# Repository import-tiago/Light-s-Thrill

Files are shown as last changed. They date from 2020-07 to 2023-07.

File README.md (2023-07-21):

# Light's Thrill

 

Light's Thrill is an USB HID controller for RGB LED-strips, compatible with Corsair iCUE application.

#### Compatible with: 
* [iCUE](https://www.corsair.com/br/pt/icue)
* [OpenRGB](https://gitlab.com/CalcProgrammer1/OpenRGB)
* [JackNet RGB Sync](https://rgbsync.com/)
* [RGB Infrared Controller](https://github.com/import-tiago/Light-s-Thrill/blob/master/Assets/RGB%20Infrared%20Controller%20Example.jpg)

## 3D Printed Enclosure
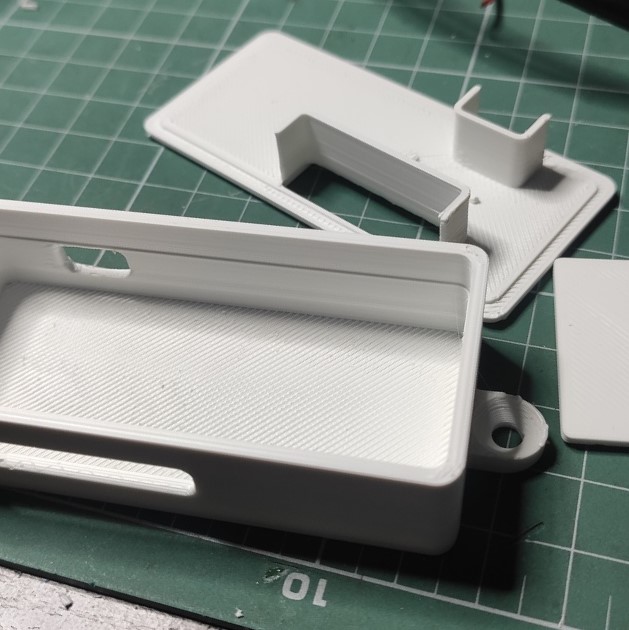
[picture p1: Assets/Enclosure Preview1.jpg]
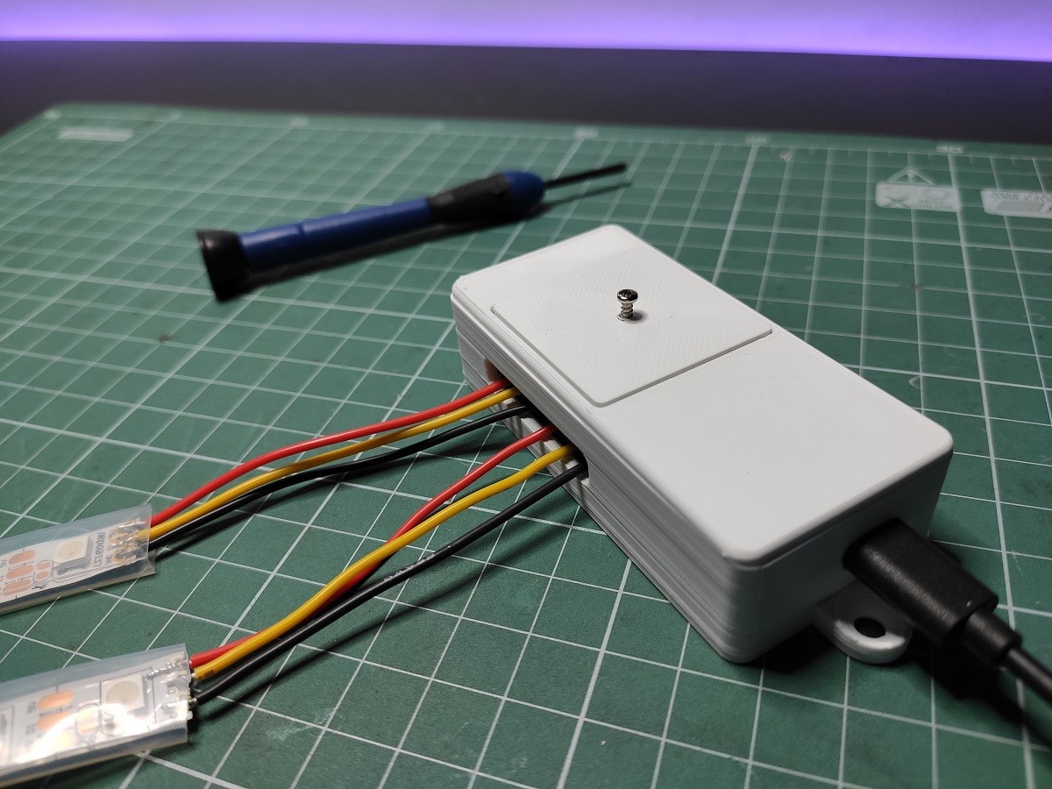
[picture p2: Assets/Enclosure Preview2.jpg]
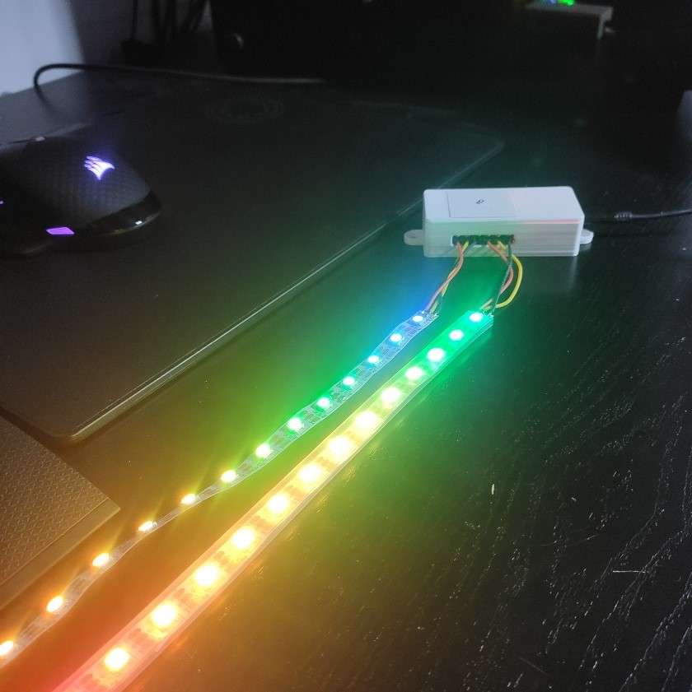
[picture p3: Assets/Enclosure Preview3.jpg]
 |  | 
--- | --- | ---

## Schematic
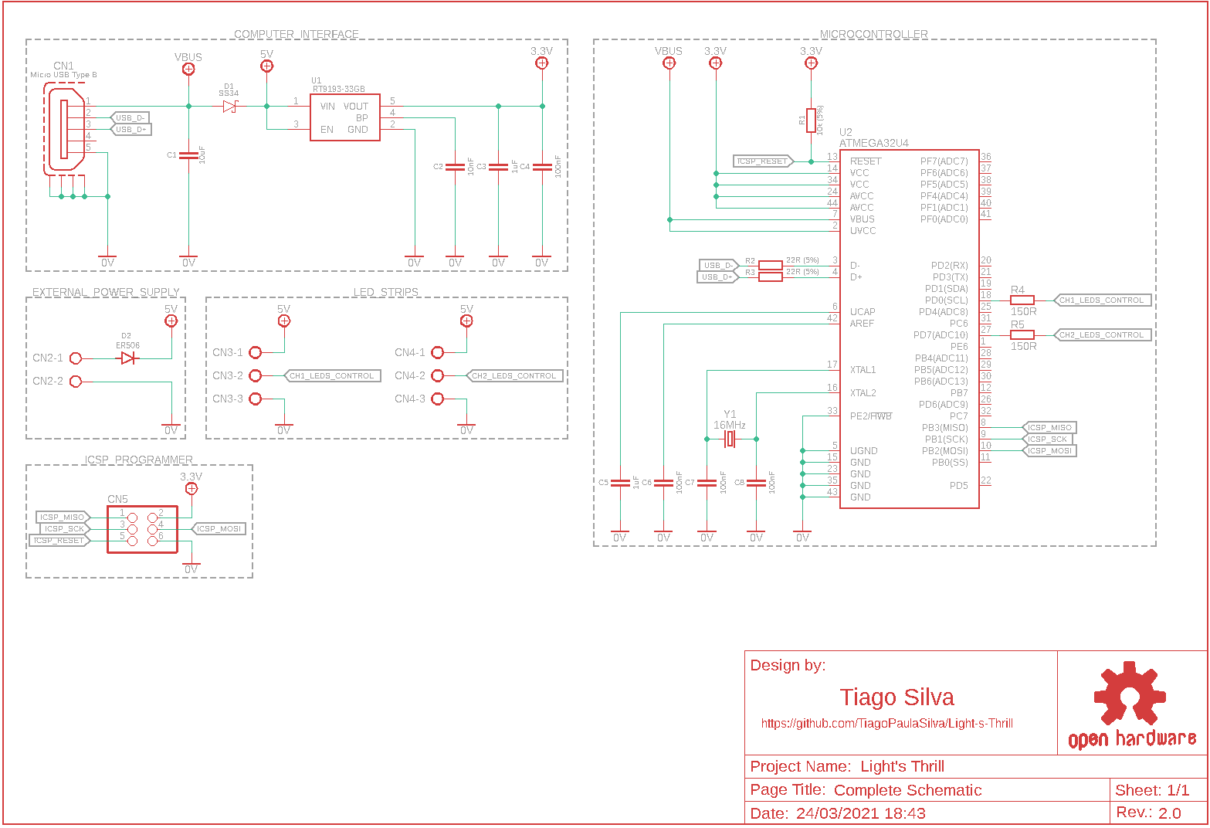
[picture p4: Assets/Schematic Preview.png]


## SETUP Parts


## MCU SETUP
- Burn the Arduino Leornado bootloader at ATmega32U4 with an Arduino UNO as ISP programmer using SPI circuit connection.
- Install the Corsair Lighting Protocol Boards to the Arduino IDE from: ```https://raw.githubusercontent.com/Legion2/CorsairLightingProtocolBoards/master/package_Legion2_CorsairLightingProtocolBoards_index.json```.
- Upload the ```Firmware\Firmware.ino``` to the ATmega32u4 as following:
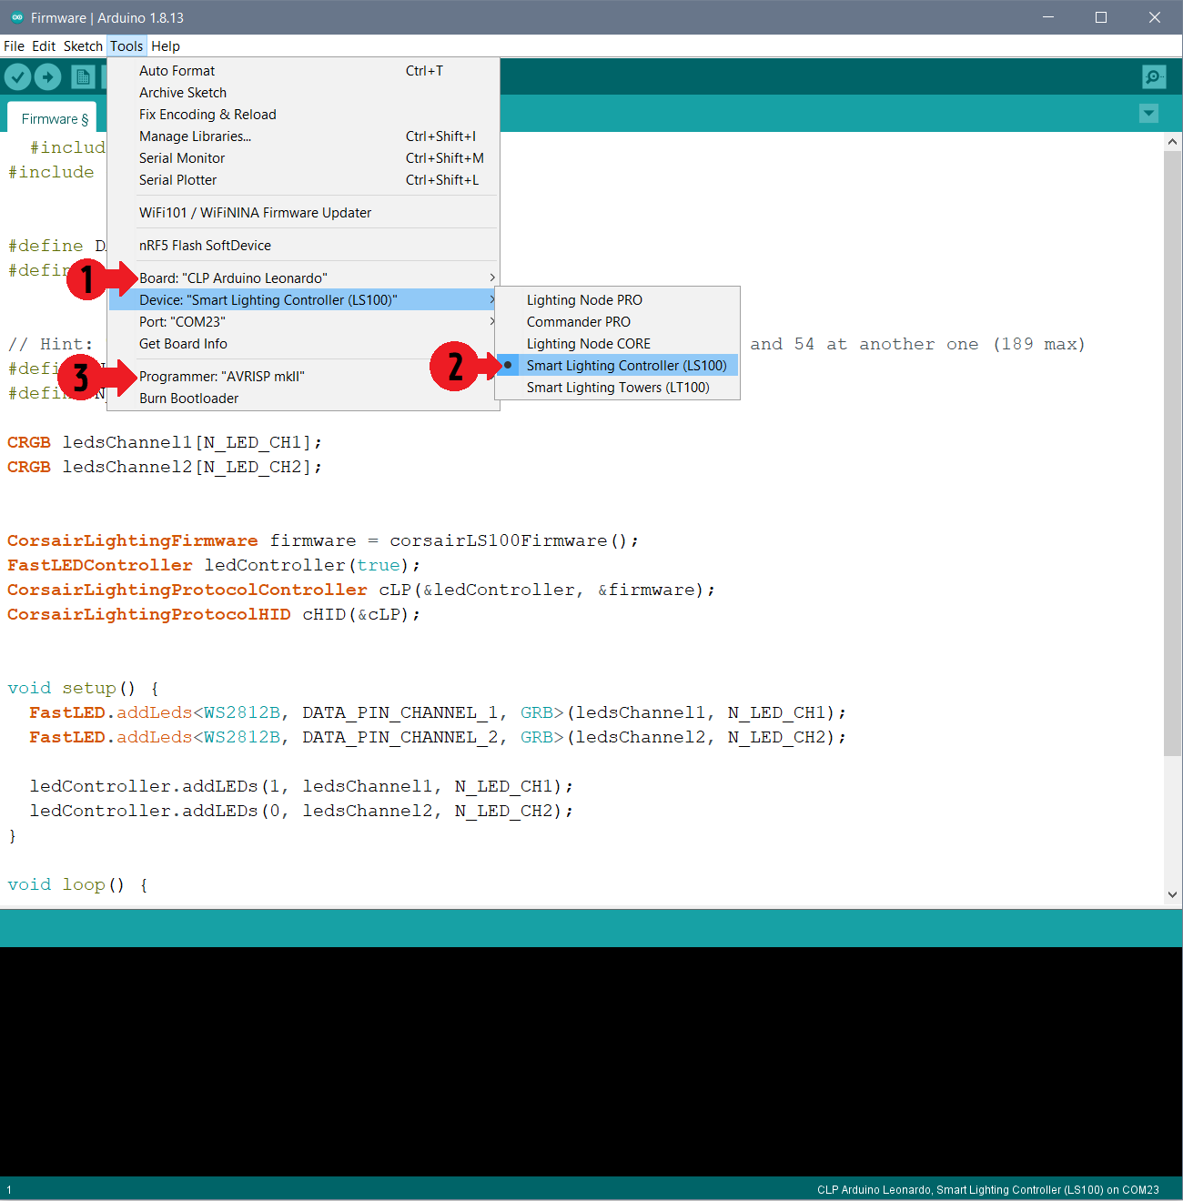
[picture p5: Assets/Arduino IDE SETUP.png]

- Done. The device is now ready to be recognized by Corsair iCUE application.

## Corsair iCUE SETUP
- To have the maximum (2x 89) of LEDs controlled by the iCUE, configure it as follows:


## Video - Demo
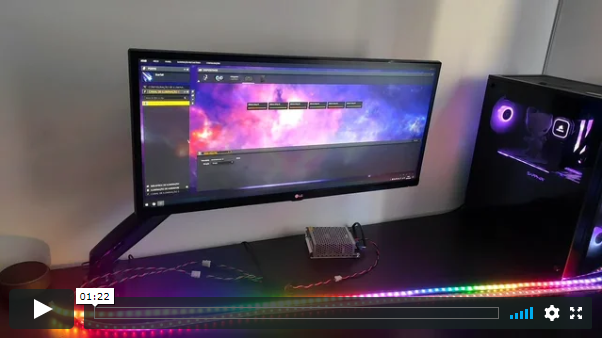
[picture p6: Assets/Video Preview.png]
Watch the video
<p align="center"></p>

### Contributing
0. Give this project a :star:
1. Create an issue and describe your idea.
2. [Fork it](https://github.com/import-tiago/Light-s-Thrill/fork).
3. Create your feature branch (`git checkout -b my-new-feature`).
4. Commit your changes (`git commit -a -m "Added feature title"`).
5. Publish the branch (`git push origin my-new-feature`).
6. Create a new pull request.
7. Done! :heavy_check_mark:

### License Information
<br /><span xmlns:dct="http://purl.org/dc/terms/" property="dct:title">Light's Thrill</span> by <a xmlns:cc="http://creativecommons.org/ns#" href="https://github.com/import-tiago" property="cc:attributionName" rel="cc:attributionURL">Tiago Silva</a> is licensed under a <a rel="license" href="http://creativecommons.org/licenses/by-sa/4.0/">Creative Commons Attribution-ShareAlike 4.0 International License</a>.<br />
Based on a work at <a xmlns:dct="http://purl.org/dc/terms/" href="[Corsair Lighting Protocol](https://github.com/import-tiago/CorsairLightingProtocol)" rel="dct:source">[Corsair Lighting Protocol](https://github.com/import-tiago/CorsairLightingProtocol)</a> and <a xmlns:dct="http://purl.org/dc/terms/" href="[Open Corsair Link](https://github.com/import-tiago/OpenCorsairLink)" rel="dct:source">[Open Corsair Link](https://github.com/import-tiago/OpenCorsairLink)</a>.<br />
Permissions beyond the scope of this license may be available at <a xmlns:cc="http://creativecommons.org/ns#" href="https://twitter.com/import_tiago" rel="cc:morePermissions">tiagodepaulasilva@gmail.com</a>.

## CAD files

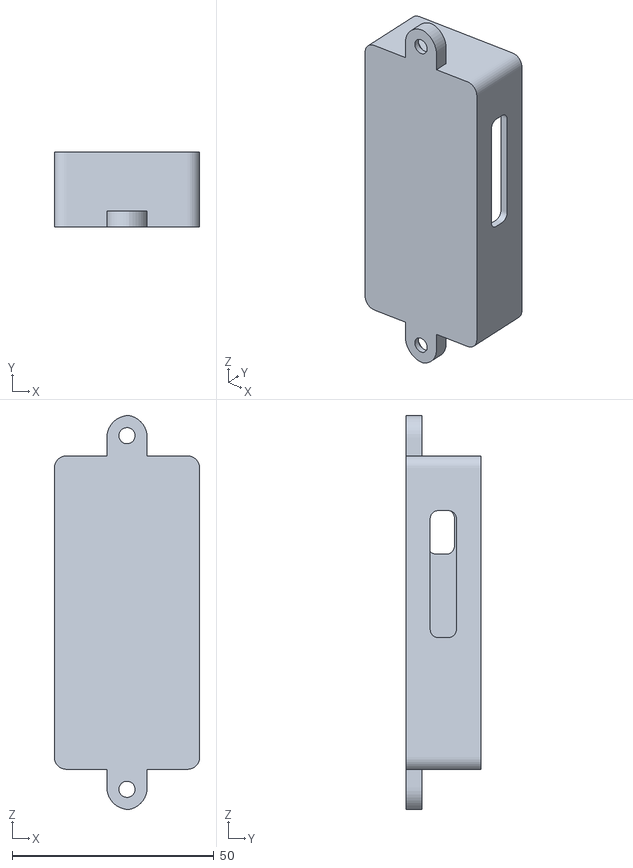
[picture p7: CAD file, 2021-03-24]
3D Models/Light's Thrill - Enclosure Box.stl
36.0 x 18.6 x 97.5

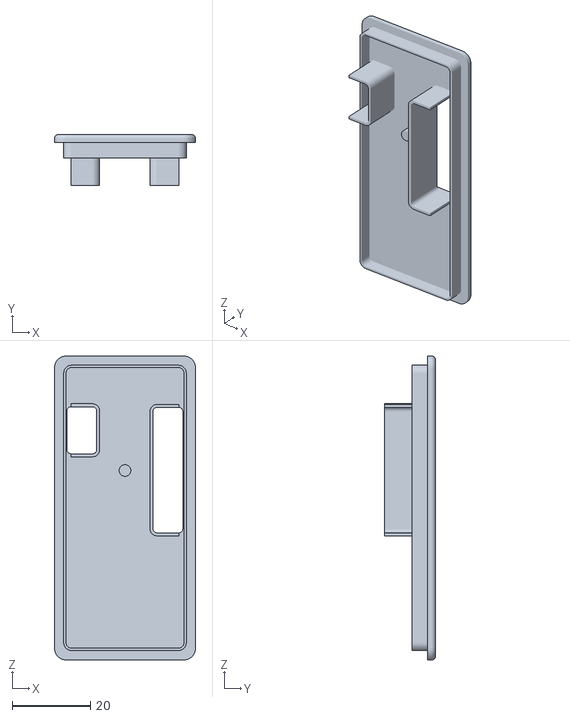
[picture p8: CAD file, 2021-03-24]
3D Models/Light's Thrill - Enclosure Cover.stl
36.0 x 13.0 x 77.6

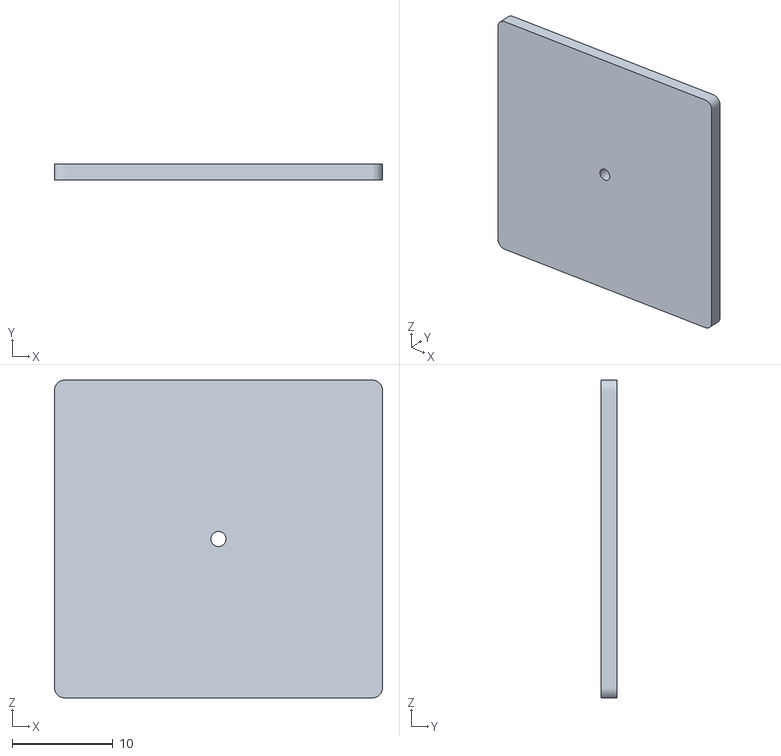
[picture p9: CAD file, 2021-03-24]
3D Models/Light's Thrill - Screws Cover.stl
32.5 x 1.60 x 31.5

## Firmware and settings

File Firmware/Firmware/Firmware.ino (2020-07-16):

#include <CorsairLightingProtocol.h>
#include <FastLED.h>
#include "IRremote.h"
#include <RGBLed.h>
#include <EEPROM.h>

#define LED_RED_PIN     5
#define LED_GREEN_PIN   9
#define LED_BLUE_PIN    10
#define IR_SENSOR_PIN   7

#define BRIGHTNESS_INCREASE   ((long)0xF700FF)
#define COLOR_RED             ((long)0xF720DF)
#define COLOR_ORANGE_RED      ((long)0xF710EF)
#define COLOR_ORANGE          ((long)0xF730CF)
#define COLOR_CORAL           ((long)0xF708F7)
#define COLOR_YELLOW          ((long)0xF728D7)
#define BRIGHTNESS_DECREASE   ((long)0xF7807F)
#define COLOR_GREEN           ((long)0xF7A05F)
#define COLOR_LIME            ((long)0xF7906F)
#define COLOR_CYAN            ((long)0xF7B04F)
#define COLOR_BABY_BLUE       ((long)0xF78877)
#define COLOR_CERULEAN        ((long)0xF7A857)
#define SWITCH_OFF            ((long)0xF740BF)
#define COLOR_BLUE            ((long)0xF7609F)
#define COLOR_AZURE           ((long)0xF750AF)
#define COLOR_BLUE_VIOLET     ((long)0xF7708F)
#define COLOR_BYZANTIUM       ((long)0xF748B7)
#define COLOR_PINK            ((long)0xF76897)
#define SWITCH_ON             ((long)0xF7C03F)
#define COLOR_WHITE           ((long)0xF7E01F)
#define EFFECT_FLASH          ((long)0xF7D02F)
#define EFFECT_STROBE         ((long)0xF7F00F)
#define EFFECT_FADE           ((long)0xF7C837)
#define EFFECT_SMOOTH         ((long)0xF7E817)

#define CONTROLLED_BY_INFRARED  0
#define CONTROLLED_BY_USB       1
bool Current_Control_Device = CONTROLLED_BY_USB;

IRrecv irrecv(7);
decode_results results;


RGBLed LED_Strip(LED_RED_PIN, LED_GREEN_PIN, LED_BLUE_PIN, COMMON_CATHODE);


int Brightness_Value = 100;



long EEPROM_Last_Color_Addr = 0;
int EEPROM_Last_Brightness_Addr = 4;

long Last_RGB_Color;
int Last_Brightness_Value;

CorsairLightingFirmware firmware = corsairLightingNodePROFirmware();
FastLEDController ledController(true);
CorsairLightingProtocolController cLP(&ledController, &firmware);
CorsairLightingProtocolHID cHID(&cLP);

CRGB ledsChannel1[1];


void setup() {

  Serial.begin(9600);

  irrecv.enableIRIn();
  pinMode(LED_RED_PIN, OUTPUT);
  pinMode(LED_GREEN_PIN, OUTPUT);
  pinMode(LED_BLUE_PIN, OUTPUT);
  pinMode(IR_SENSOR_PIN, INPUT);
  ledController.addLEDs(0, ledsChannel1, 1);
  ledController.onUpdateHook(0, []() {
    // use color of first LED of the first channel
    set4PinLEDs(ledsChannel1[0]);
  });

  Restore_Last_Adjustments();

  Current_Control_Device = CONTROLLED_BY_USB;
}

void loop() {
  if(Current_Control_Device == CONTROLLED_BY_USB){
    cHID.update();
    ledController.updateLEDs();
  }
  readIR();
}

void set4PinLEDs(const CRGB& color) {
  analogWrite(LED_RED_PIN, color.r);
  analogWrite(LED_GREEN_PIN, color.g);
  analogWrite(LED_BLUE_PIN, color.b);
}


void Restore_Last_Adjustments() {

  EEPROM.get(EEPROM_Last_Color_Addr, Last_RGB_Color);
  EEPROM.get(EEPROM_Last_Brightness_Addr, Last_Brightness_Value);
  Run_IR_Command(Last_RGB_Color);
  LED_Strip.brightness(Last_Brightness_Value);
}

void readIR() {
  if (irrecv.decode( &results )) {
    unsigned long IRval = results.value;
    if (IRval == 0xFFFFFFFF) { // 0xFFFFFFFF is the "repeat code" sent when a button is held down
      irrecv.resume();
      return;
    }
    //Serial.println( results.value, HEX);
    Run_IR_Command(results.value);
    irrecv.resume();
  }
}

void Run_IR_Command(long Code_Received) {

  bool Color_Adjustment = false;

  switch (Code_Received) {

    case SWITCH_ON:
      Serial.println("SWITCH_ON");

      LED_Strip.brightness(Brightness_Value);
      Current_Control_Device = CONTROLLED_BY_INFRARED;

      break;

    case SWITCH_OFF:
      Serial.println("SWITCH_OFF");
      digitalWrite(LED_RED_PIN, LOW);
      digitalWrite(LED_GREEN_PIN, LOW);
      digitalWrite(LED_BLUE_PIN, LOW);
      Current_Control_Device = CONTROLLED_BY_USB;

      break;

    case BRIGHTNESS_INCREASE:
      Serial.println("BRIGHTNESS_INCREASE");
      if (Brightness_Value < 100)
        Brightness_Value += 20;
      LED_Strip.brightness(Brightness_Value);
      EEPROM.put(EEPROM_Last_Brightness_Addr, Brightness_Value);
      Current_Control_Device = CONTROLLED_BY_INFRARED;
      break;

    case BRIGHTNESS_DECREASE:
      Serial.println("BRIGHTNESS_DECREASE");
      if (Brightness_Value > 0)
        Brightness_Value -= 20;
      LED_Strip.brightness(Brightness_Value);
      EEPROM.put(EEPROM_Last_Brightness_Addr, Brightness_Value);
      Current_Control_Device = CONTROLLED_BY_INFRARED;
      break;

    case COLOR_RED:
      Serial.println("COLOR_RED");
      LED_Strip.setColor(RGBLed::RED);
      Color_Adjustment = true;
      Current_Control_Device = CONTROLLED_BY_INFRARED;
      break;

    case COLOR_ORANGE_RED:
      Serial.println("COLOR_ORANGE_RED");
      LED_Strip.setColor(RGBLed::ORANGE_RED);
      Color_Adjustment = true;
      Current_Control_Device = CONTROLLED_BY_INFRARED;
      break;

    case COLOR_ORANGE:
      Serial.println("COLOR_ORANGE");
      LED_Strip.setColor(RGBLed::ORANGE);
      Color_Adjustment = true;
      Current_Control_Device = CONTROLLED_BY_INFRARED;
      break;

    case COLOR_CORAL:
      Serial.println("COLOR_CORAL");
      LED_Strip.setColor(RGBLed::CORAL);
      Color_Adjustment = true;
      Current_Control_Device = CONTROLLED_BY_INFRARED;
      break;

    case COLOR_YELLOW:
      Serial.println("COLOR_YELLOW");
      LED_Strip.setColor(RGBLed::YELLOW);
      Color_Adjustment = true;
      Current_Control_Device = CONTROLLED_BY_INFRARED;
      break;

    case COLOR_GREEN:
      Serial.println("COLOR_GREEN");
      LED_Strip.setColor(RGBLed::GREEN);
      Color_Adjustment = true;
      Current_Control_Device = CONTROLLED_BY_INFRARED;
      break;

    case COLOR_LIME:
      Serial.println("COLOR_LIME");
      LED_Strip.setColor(RGBLed::LIME);
      Color_Adjustment = true;
      Current_Control_Device = CONTROLLED_BY_INFRARED;
      break;

    case COLOR_CYAN:
      Serial.println("COLOR_CYAN");
      LED_Strip.setColor(RGBLed::CYAN);
      Color_Adjustment = true;
      Current_Control_Device = CONTROLLED_BY_INFRARED;
      break;

    case COLOR_BABY_BLUE:
      Serial.println("COLOR_BABY_BLUE");
      LED_Strip.setColor(RGBLed::BABY_BLUE);
      Color_Adjustment = true;
      Current_Control_Device = CONTROLLED_BY_INFRARED;
      break;

    case COLOR_CERULEAN:
      Serial.println("COLOR_CERULEAN");
      LED_Strip.setColor(RGBLed::CERULEAN);
      Color_Adjustment = true;
      Current_Control_Device = CONTROLLED_BY_INFRARED;
      break;

    case COLOR_BLUE:
      Serial.println("COLOR_BLUE");
      LED_Strip.setColor(RGBLed::BLUE);
      Color_Adjustment = true;
      Current_Control_Device = CONTROLLED_BY_INFRARED;
      break;

    case COLOR_AZURE:
      Serial.println("COLOR_AZURE");
      LED_Strip.setColor(RGBLed::AZURE);
      Color_Adjustment = true;
      Current_Control_Device = CONTROLLED_BY_INFRARED;
      break;

    case COLOR_BLUE_VIOLET:
      Serial.println("COLOR_BLUE_VIOLET");
      LED_Strip.setColor(RGBLed::BLUE_VIOLET);
      Color_Adjustment = true;
      Current_Control_Device = CONTROLLED_BY_INFRARED;
      break;

    case COLOR_BYZANTIUM:
      Serial.println("COLOR_BYZANTIUM");
      LED_Strip.setColor(RGBLed::BYZANTIUM);
      Color_Adjustment = true;
      Current_Control_Device = CONTROLLED_BY_INFRARED;
      break;

    case COLOR_PINK:
      Serial.println("COLOR_PINK");
      LED_Strip.setColor(RGBLed::PINK);
      Color_Adjustment = true;
      Current_Control_Device = CONTROLLED_BY_INFRARED;
      break;

    case COLOR_WHITE:
      Serial.println("COLOR_WHITE");
      LED_Strip.setColor(RGBLed::WHITE);
      Color_Adjustment = true;
      Current_Control_Device = CONTROLLED_BY_INFRARED;
      break;

    case EFFECT_FLASH:
      Serial.println("EFFECT_FLASH");
      break;

    case EFFECT_STROBE:
      Serial.println("EFFECT_STROBE");
      break;

    case EFFECT_FADE:
      Serial.println("EFFECT_FADE");
      break;

    case EFFECT_SMOOTH:
      Serial.println("EFFECT_SMOOTH");
      break;
  }

  if (Color_Adjustment == true)
    EEPROM.put(EEPROM_Last_Color_Addr, Code_Received);
}

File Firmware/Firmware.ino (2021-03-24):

#include <CorsairLightingProtocol.h>
#include <FastLED.h>


#define DATA_PIN_CHANNEL_1 6
#define DATA_PIN_CHANNEL_2 3


// Hint: The ATmega32U4 does not have enough memory! MAX 135 at ch1 and 54 at another one (189 max)
#define N_LED_CH1 89
#define N_LED_CH2 89

CRGB ledsChannel1[N_LED_CH1];
CRGB ledsChannel2[N_LED_CH2];


CorsairLightingFirmware firmware = corsairLS100Firmware();
FastLEDController ledController(true);
CorsairLightingProtocolController cLP(&ledController, &firmware);
CorsairLightingProtocolHID cHID(&cLP);


void setup() {
  FastLED.addLeds<WS2812B, DATA_PIN_CHANNEL_1, GRB>(ledsChannel1, N_LED_CH1);
  FastLED.addLeds<WS2812B, DATA_PIN_CHANNEL_2, GRB>(ledsChannel2, N_LED_CH2);
  
  ledController.addLEDs(1, ledsChannel1, N_LED_CH1);
  ledController.addLEDs(0, ledsChannel2, N_LED_CH2);  
}

void loop() {
 
	cHID.update();
  
	if (ledController.updateLEDs()) {
		FastLED.show();
	} 
}

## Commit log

2020-07-11 Schematic 1.0 - DONE
    [Light's Thrill.sch]
2020-07-11 Schematic preview generated
2020-07-11 Schematic Preview margin removed
2020-07-12 Schematic 1.1 - DONE
    - User's interface circuit added (button and LED)
    - 12V to 5V LDO added (working without a computer)
    - External power supply circuit detect added
    [Light's Thrill.sch]
2020-07-12 Schematic Preview image margin removed
2020-07-12 Minimum PWM/MOSFET firmware test
2020-07-12 Schematic 1.2 - Minor improvements
    [Light's Thrill.sch]
2020-07-12 Schematic Preview updated to 1.2 revision
2020-07-12 PCB Layout 1.2 - DONE
    [Light's Thrill.brd, Light's Thrill.sch]
2020-07-12 Gerbers Files - PCB 1.2
2020-07-12 Schematic + PCB 1.3 up to date
    - Change MCU_PWM_RED to a 16 bit PWM pin.
    [Light's Thrill.brd, Light's Thrill.sch]
2020-07-12 Schematic image preview updated to 1.3 PCB revision
2020-07-13 ICSP Programming added (PCB 1.4)
    [Light's Thrill.brd, Light's Thrill.sch]
2020-07-13 Minimum RGB and PWM/MOSFET firmware test
2020-07-16 Enclosure Preview image rendered
2020-07-17 Minor PCB improvements
    [Light's Thrill.brd]
2020-07-17 PCB preview image rendered
2021-03-24 Code updated with the latest libraries versions
    [Light's Thrill - Enclosure Box.stl, Light's Thrill - Enclosure Cover.stl, Light's Thrill - Screws Cover.stl]
2021-03-24 New images and directory structure
    [Light's Thrill.brd, Light's Thrill.sch]
2021-03-31 LEDs datasheet added
